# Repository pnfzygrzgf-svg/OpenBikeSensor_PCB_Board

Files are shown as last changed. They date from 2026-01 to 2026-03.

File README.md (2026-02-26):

# OpenBikeSensor PCB

**Hinweis:** Dieses Repository ist ein Klon/Fork des offiziellen
[OpenBikeSensor PCB-Repositories](https://github.com/openbikesensor/OpenBikeSensor_PCB_Board) und enthält zusätzliche Erweiterungen.

**Neu in diesem Fork:**
- **OpenBikeSensor Lite LiDAR** (`OpenBikeSensorLiteLidar/`) — PCB-Variante mit 2x TF-Luna LiDAR statt Ultraschallsensoren

## Versionen

### OpenBikeSensor Lite LiDAR

Im Verzeichnis `OpenBikeSensorLiteLidar` findest du die Dateien für das Modell
OpenBikeSensor Lite LiDAR (2x TF-Luna). Diese Variante basiert auf dem Lite-Konzept
(Messelektronik + Kommunikation, Programmlogik überwiegend auf dem Handy), nutzt
aber LiDAR zur Abstandsmessung.

* [Gerber (ZIP)](./OpenBikeSensorLiteLidar/plot/OpenBikeSensorLiteLidar-gerbers.zip)
* [KiCad PCB](./OpenBikeSensorLiteLidar/OpenBikeSensorLiteLidar.kicad_pcb)

### OpenBikeSensor

OpenBikeSensor 3D-Render

Dies ist der Standard-OpenBikeSensor als eigenständiges Gerät, hergestellt aus
vielen fertig verfügbaren Modulen (ESP32 Devkit, GPS, SD-Karten-Modul,
Ultraschallsensor-Module, ...).

Die aktuelle Versionsnummer des OpenBikeSensor Clasic PCB ist `1.0.0`. Den veralteten Repositorystand der Vorversion findest du [hier](https://github.com/openbikesensor/OpenBikeSensor_PCB_Board/tree/00.03.12)

* [Gerber](OpenBikeSensor1.0.0-Gerber.zip)
* [Schaltplan, PDF](./OpenBikeSensor/generated/OpenBikeSensor-1.0.0-schematic.pdf)
* [Bestückungsplan, HTML](./OpenBikeSensor/generated/OpenBikeSensor-1.0.0-ibom.html)

### OpenBikeSensor Lite

Im Verzeichnis OpenBikeSensorLite findest du die Dateien für das Modell
OpenBikeSensor Lite. Dieser OpenBikeSensor hat nur Messelektronik,
Datenspeicher, Kommunikation und ein Großteil der Programmlogik läuft
auf dem Handy in der SimRa App.

### OpenBikeSensor Pro

Diese Variante des OpenBikeSensor ist ein vollständiger Nachbau aller
relevanter Teile der vorher als Modul gelieferten Funktionen in einer eigenen
Schaltung, und ist komplett maschinenbestückt bestellbar. Dies macht das Gerät
teurer und komplizierter herstellen zu lassen, aber es ist ein wesentlich
geringerer Eigenaufwand zur Fertigstellung ohne Löten elektronischer Module
nötig. Dieses Projekt is zur Zeit in der Entwicklung und hoffentlich im Laufe
des Jahres 2023 benutzbar.

## Bestellung bei Platinenherstellern

Ein Export der Projektdateien als "Gerber-Files" liegt im jeweiligen
Projektordner vor. Die meisten Hersteller von Platinen bieten einen
Online-Konfigurator an, in den diese Dateien hochgeladen werden können, und
welcher dann auch eine Vorschau bietet. In der Regel sollten diese Exports für
alle Hersteller funktionieren, die Anforderungen an die Genauigkeit der
Produktion sind relativ gering.

Die Standardeinstellungen für die Platine sind in der Regel vollkommen
ausreichend, das ist üblicherweise ein 2-Layer Board mit einfachem Surface
Finish (HASL) in 1.6mm Stärke (FR-4) und 1oz Kupferstärke. Bessere Optionen (z.
B. ENIG) sind möglich, aber nicht nötig. Die Einstellungen können nach Belieben
angepasst werden, insbesondere ästhetische Aspekte wie die Farbe der Boards.

Einige Hersteller (z. B. Aisler) können die KiCad-Dateien direkt importieren,
hier muss nur die `.kicad_pcb` Datei ausgewählt werden, diese enthält alle
Informationen des Designs.

Bei manchen Herstellern (z. B. JLCPCB) wird die Bestellnummer auf jedes Board
aufgedruckt, für einen kleinen Mehrbetrag kann dies vermieden werden. Gerade
bei größeren Bestellungen fällt diese Gebühr kaum ins Gewicht und ist sehr zu
empfehlen.

## Lizenz

Die eigenen Inhalte dieses Repositories sind lizensiert unter den Bedingungen
der GNU Lesser General Public License. Eine Kopie der Lizenz befindet sich in der
Datei `LICENSE` in diesem Verzeichnis.

Nicht unter diese Lizenz fallen:

* Die folgenden Dateien, welche leichte Modifikationen von Standard-Footprints
  der KiCad-Bibliothek sind und somit unter der entsprechende Lizenz
  ([CC-BY-SA 4.0 mit Modifikationen](https://www.kicad.org/libraries/license/))
  stehen:
    - `libs/OpenBikeSensor.pretty/CP_Radial_D4.0mm_P1.50mm.kicad_mod`
    - `libs/OpenBikeSensor.pretty/Connector_1x02.kicad_mod`
    - `libs/OpenBikeSensor.pretty/Connector_1x04.kicad_mod`
    - `libs/OpenBikeSensor.pretty/Connector_1x05_Display.kicad_mod`
    - `libs/OpenBikeSensor.pretty/Connector_1x06.kicad_mod`

## Update der Exportdateien

Die Dateien in `generated` können mit
[KiBot](https://github.com/INTI-CMNB/KiBot) automatisch aktualisiert werden.
Eine Konfigurationsdatei liegt im jeweiligen Projektverzeichnis vor. Ein
Ausführen von `kibot` im entsprechenden Unterverzeichnis (z. B. `cd
OpenBikeSensor`) erstellt alle Exportdateien neu. Bitte checke nur solche
Dateien in git ein, welche du in deinem Commit auch inhaltlich verändert hast
(z. B. den PDF Schaltplanexport wenn der Schaltplan verändert wurde, aber nicht
wenn nur das PCB Änderungen hat).

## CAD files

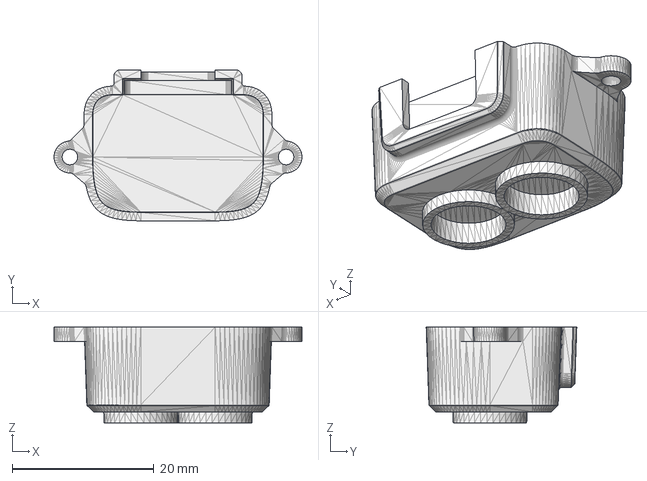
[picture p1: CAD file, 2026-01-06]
OpenBikeSensorLiteLidar/tfluna.step
35.0 x 21.2 x 13.5 mm

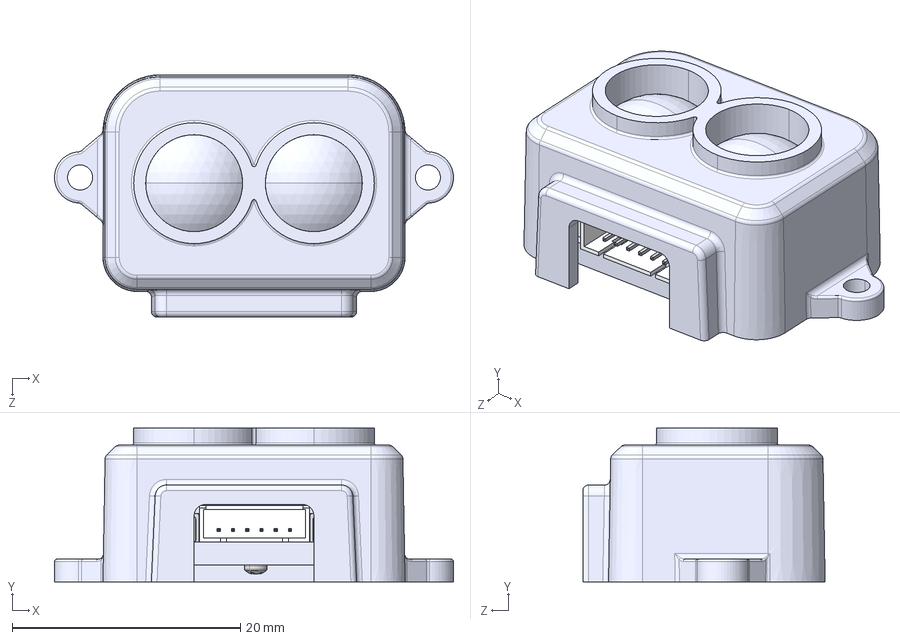
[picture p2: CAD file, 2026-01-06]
OpenBikeSensorLiteLidar/AssemBeneWake TF-LUNA.STEP
35.0 x 13.5 x 21.2 mm
BeneWake TF-LUNA
pan_head_phillip_mc_screw_m1 x 3
JST - GH - SMD (R) - 6Pin - 1.25mm

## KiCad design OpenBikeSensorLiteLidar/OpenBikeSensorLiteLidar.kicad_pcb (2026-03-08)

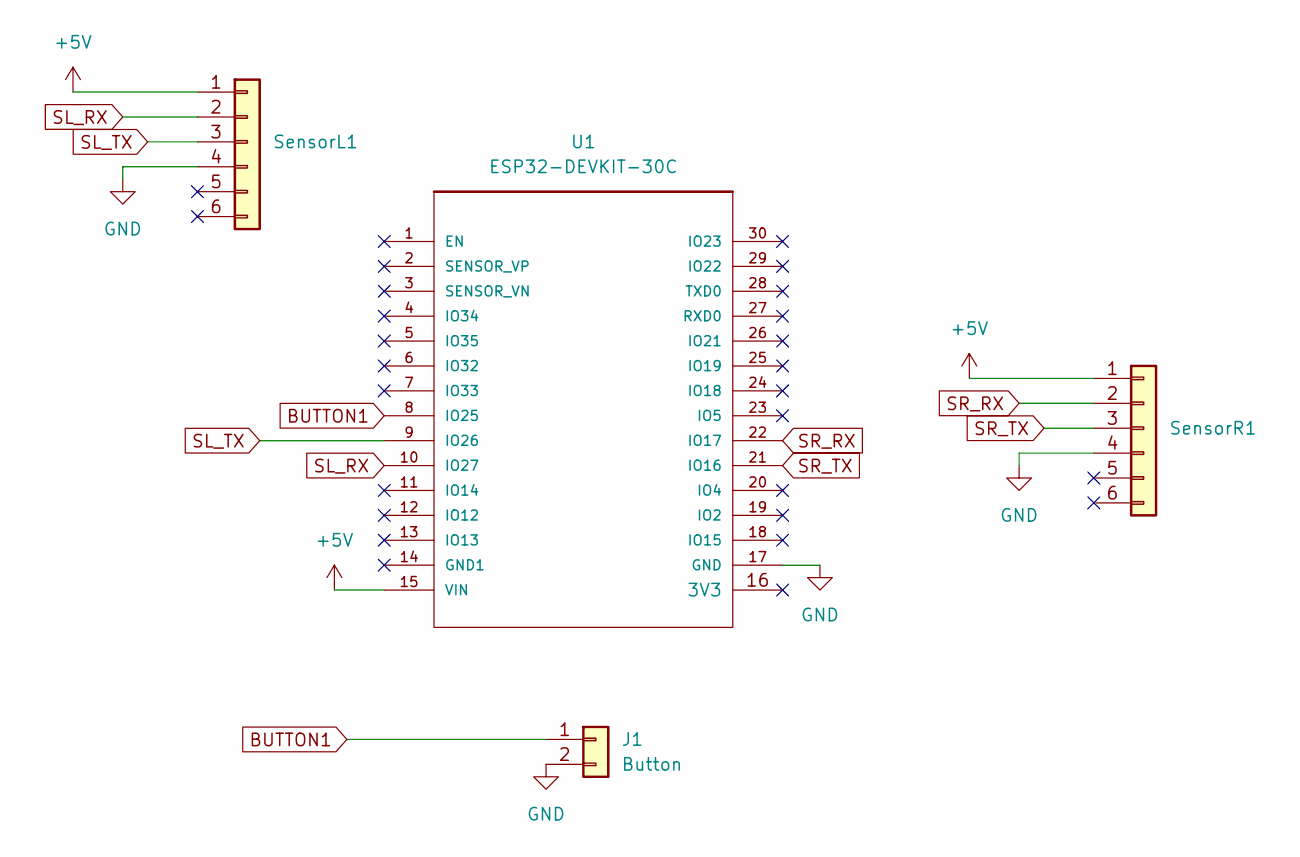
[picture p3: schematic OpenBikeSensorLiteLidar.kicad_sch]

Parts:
J1: Button; JST_EH_S2B-EH_1x02_P2.50mm_Horizontal
SensorL1: Conn_01x06; JST_XH_B6B-XH-A_1x06_P2.50mm_Vertical
SensorR1: Conn_01x06; JST_XH_B6B-XH-A_1x06_P2.50mm_Vertical
U1: ESP32-DEVKIT-30C; ESP32-WROOM-30-THT

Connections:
+5V: SensorL1.1, SensorR1.1, U1.15 (VIN)
BUTTON1: J1.1, U1.8 (IO25)
GND: J1.2, SensorL1.4, SensorR1.4, U1.17 (GND)
SL_RX: SensorL1.2, U1.10 (IO27)
SL_TX: SensorL1.3, U1.9 (IO26)
SR_RX: SensorR1.2, U1.22 (IO17)
SR_TX: SensorR1.3, U1.21 (IO16)

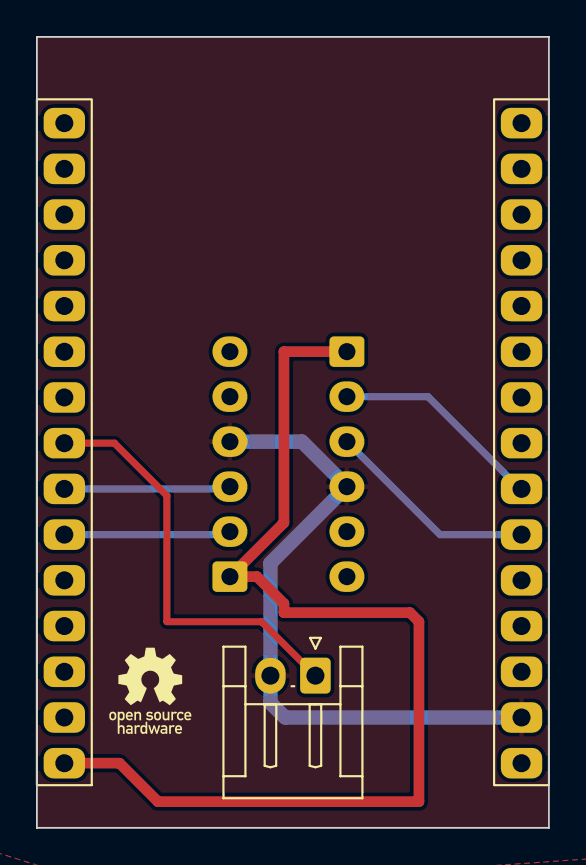
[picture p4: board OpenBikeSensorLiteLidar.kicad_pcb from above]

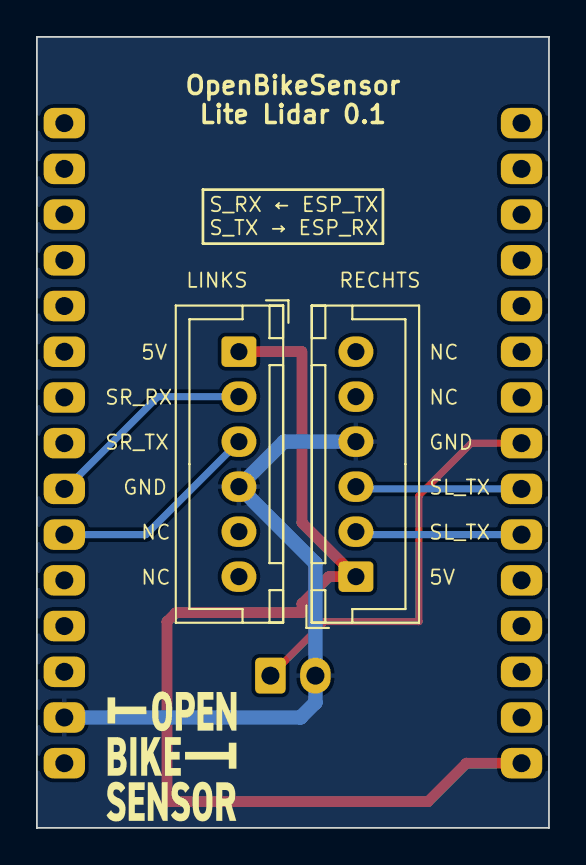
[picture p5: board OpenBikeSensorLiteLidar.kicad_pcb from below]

Board: 2 copper layers, 28.4 x 43.9 mm, 4 parts (2 on the bottom side), 7 nets.

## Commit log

2026-01-06 PCB für einen OpenBikeSensorLite mit Lidarsensoren
    [AssemBeneWake TF-LUNA.STEP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]
2026-01-06 Ignore KiCad lock/autosave files
2026-01-15 Swap L/R labels on Lite LiDAR PCB; update gerbers + zip
    [OpenBikeSensorLiteLidar-B_Cu.gbr, OpenBikeSensorLiteLidar-B_Mask.gbr, OpenBikeSensorLiteLidar-B_Silkscreen.gbr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]
2026-02-26 Update fork notice with LiDAR PCB additions and L/R label fix
2026-02-27 Lizenz hinzugefügt
    [OpenBikeSensorLiteLidar.kicad_pcb, OpenBikeSensorLiteLidar.kicad_sch]
2026-03-08 Open-Source-Hardware Logo
    [OpenBikeSensorLiteLidar-B_Cu.gbr, OpenBikeSensorLiteLidar-B_Mask.gbr, OpenBikeSensorLiteLidar-B_Silkscreen.gbr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]

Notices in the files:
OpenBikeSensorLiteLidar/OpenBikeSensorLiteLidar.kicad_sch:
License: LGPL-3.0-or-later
